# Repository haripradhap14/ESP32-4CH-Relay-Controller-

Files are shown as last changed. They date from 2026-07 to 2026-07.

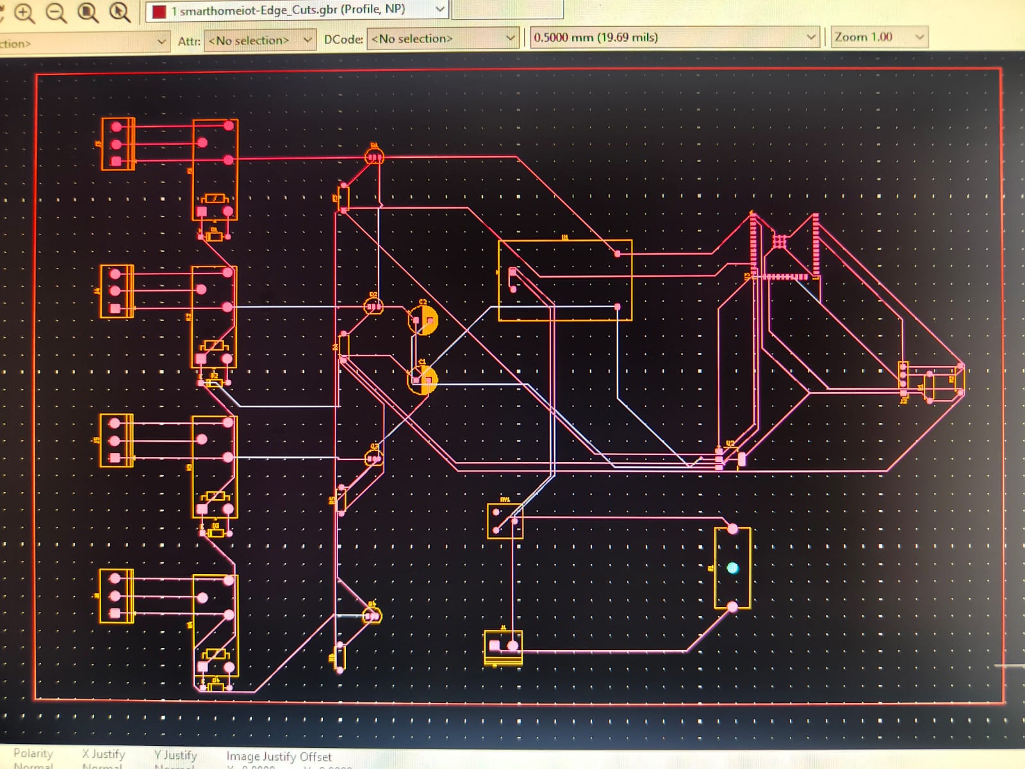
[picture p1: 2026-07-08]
Pcb_top_view.png.jpeg

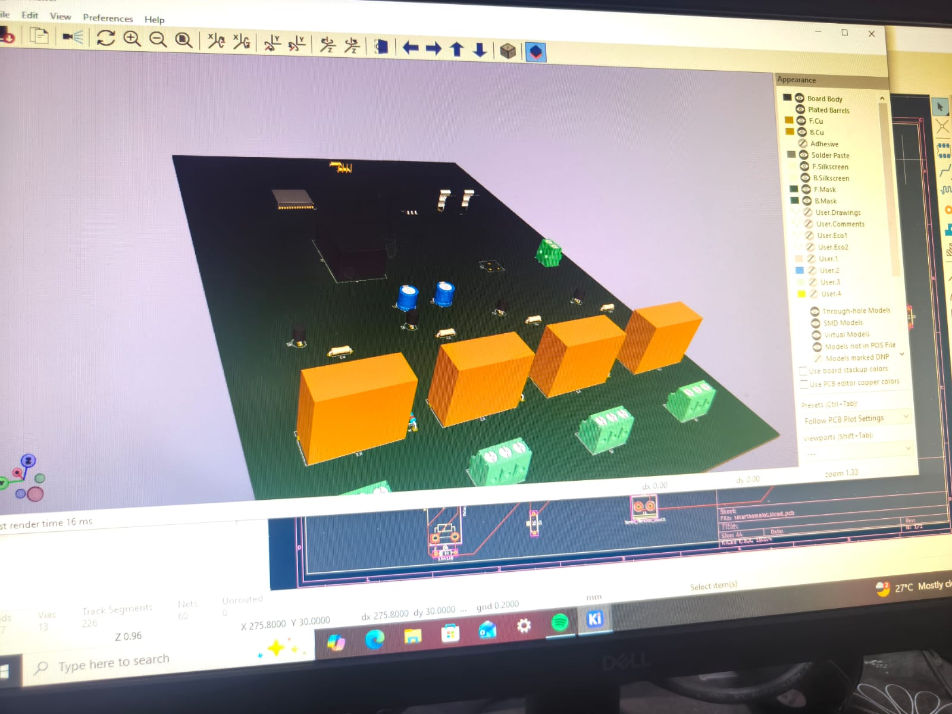
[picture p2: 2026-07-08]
Pcb_3d_render.png.jpeg

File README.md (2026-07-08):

# Smart Home Automation Controller (4-Channel Relay)

This project is a compact and integrated **Smart Home Automation Controller** designed using KiCad. It allows users to control household appliances remotely via Wi-Fi, leveraging the power of the ESP32-WROOM-32E module.

## 🚀 Key Features
* **Microcontroller:** ESP32-WROOM-32E (Integrated Wi-Fi & Bluetooth connectivity).
* **Power Management:**
    * Integrated AC-to-DC converter (230V AC to 5V DC).
    * High-efficiency 5V to 3.3V step-down regulator for stable power supply to the ESP32.
* **Control Unit:** 4-Channel Relay board to switch high-voltage home appliances (lights, fans, etc.).
* **Design:** Compact, single-board design suitable for wall-mount enclosures.
* **Flexibility:** The board is designed to be modular, allowing users to adapt inputs/switches based on specific smart home requirements.

## 🛠 Technical Specifications
* **Controller:** ESP32-WROOM-32E
* **Relay Channels:** 4 x High-quality relays with opto-isolation (for safety).
* **PCB Layers:** 2-Layer Board (FR4 material).
* **Design Software:** KiCad EDA.

## ⚠️ Safety Warning
This project involves dealing with **230V AC Mains voltage**. Please ensure all high-voltage connections are properly insulated and handled with extreme caution during testing and installation.

## 📂 Project Structure
* `/Schematic` - Contains the circuit design and architecture.
* `/PCB` - Contains the PCB layout (.kicad_pcb file).
* `/Gerbers` - Contains the manufacturing files (Gerber & Drill files) for PCB fabrication.

---
*Designed for home automation enthusiasts and IoT developers.*

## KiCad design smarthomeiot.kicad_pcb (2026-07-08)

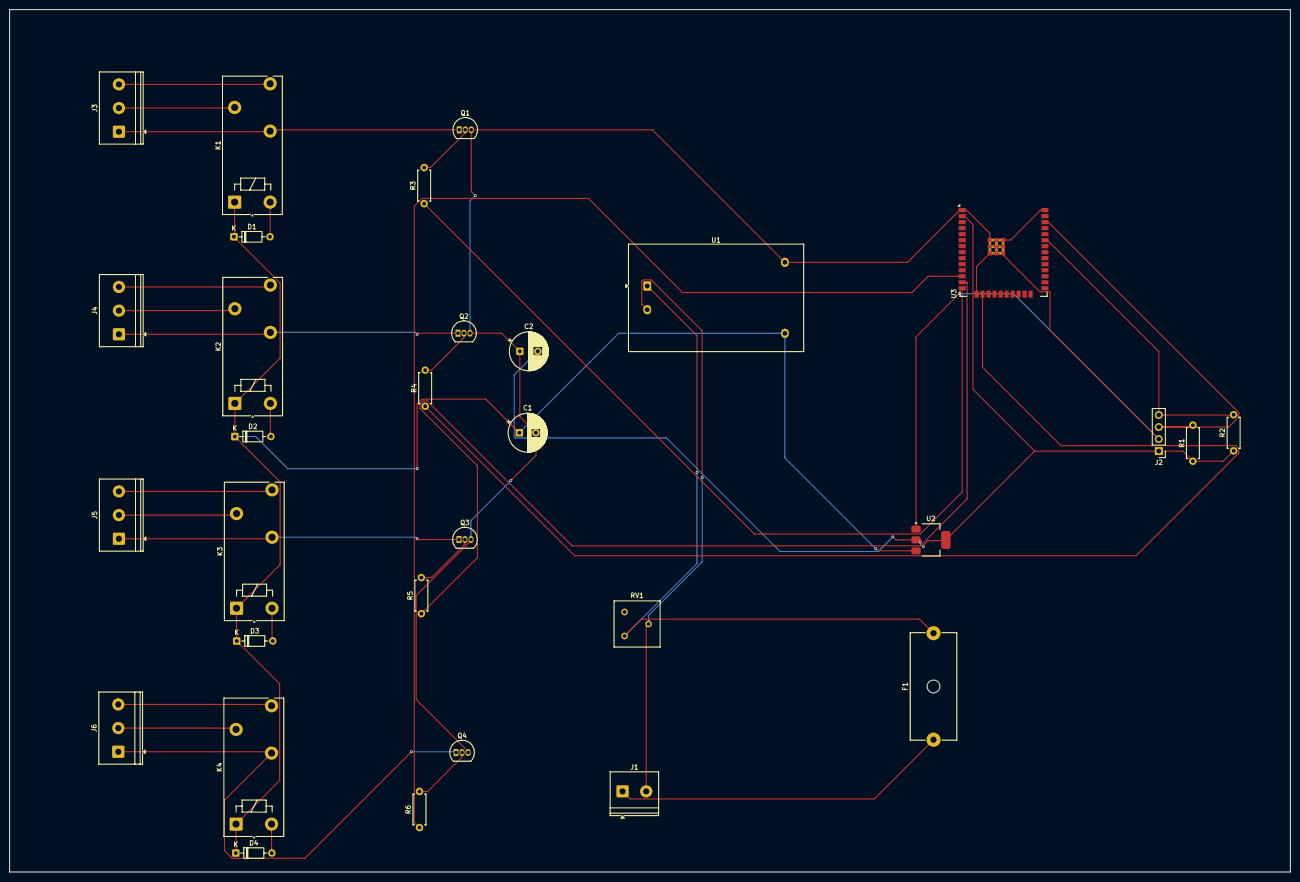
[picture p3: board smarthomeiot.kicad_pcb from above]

Board: 2 copper layers, 270.6 x 182.2 mm, 31 parts (0 on the bottom side), 32 nets.

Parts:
C1: 470uF/25V; CP_Radial_D8.0mm_P3.50mm
C2: 100uF/16V; CP_Radial_D8.0mm_P3.80mm
D1, D2, D3, D4: 1N4148; D_DO-35_SOD27_P7.62mm_Horizontal
F1: 500mA-1A; Fuseholder_Cylinder-5x20mm_Schurter_0031_8201_Horizontal_Op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
J1: Screw_Terminal_01x02; TerminalBlock_Phoenix_PT-1,5-2-5.0-H_1x02_P5.00mm_Horizontal
J2: Conn_01x04_Socket; PinHeader_1x04_P2.54mm_Vertical
J3, J4, J5, J6: Screw_Terminal_01x03; TerminalBlock_Phoenix_PT-1,5-3-5.0-H_1x03_P5.00mm_Horizontal
K1, K2, K3, K4: Relay_SPDT; Relay_SPDT_Finder_40.51
Q1, Q2, Q3, Q4: BC547; TO-92_Inline
R1, R2, R3, R4, R5, R6: 1k; R_Axial_DIN0207_L6.3mm_D2.5mm_P7.62mm_Horizontal
RV1: 275V Varistor; Potentiometer_Bourns_3386F_Vertical
U1: HLK-PM01; Converter_ACDC_Hi-Link_HLK-PMxx
U2: AMS1117-3.3; SOT-223-3_TabPin2
U3: ESP32-WROOM-32E

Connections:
+3V3: C2.2, J2.1, R1.1, R2.1, U2.2 (VO), U3.2 (VDD)
+5V: C1.1, D1.1 (K), D2.1 (K), D3.1 (K), D4.1 (K), K1.A1, K2.A1, K3.A1, K4.A1, U1.4 (+Vout), U2.3 (VI)
/ESP32_Controller/Relay_1: R3.1, U3.14 (IO12)
/ESP32_Controller/Relay_2: R4.1, U3.16 (IO13)
/ESP32_Controller/Relay_3: R5.1, U3.13 (IO14)
/ESP32_Controller/Relay_4: R6.1, U3.12 (IO27)
GND: C1.2, C2.1, J2.2, Q1.3 (E), Q2.3 (E), Q3.3 (E), Q4.3 (E), U1.3 (-Vout), U2.1 (GND), U3.1 (GND), U3.15 (GND), U3.38 (GND), U3.39 (GND)
unnamed: D1.2 (A), K1.A2
unnamed: D2.2 (A), K2.A2
unnamed: D3.2 (A), K3.A2
unnamed: D4.2 (A), K4.A2
unnamed: F1.1, J1.1
unnamed: J1.2, RV1.2, U1.2 (AC/N)
unnamed: J2.3, R1.2, U3.36 (IO22)
unnamed: J2.4, R2.2, U3.33 (IO21)
unnamed: J3.1, K1.12, Q1.1 (C)
unnamed: J3.2, K1.11
unnamed: J3.3, K1.14
unnamed: J4.1, K2.12, Q2.1 (C)
unnamed: J4.2, K2.11
unnamed: J4.3, K2.14
unnamed: J5.1, K3.12, Q3.1 (C)
unnamed: J5.2, K3.11
unnamed: J5.3, K3.14
unnamed: J6.1, K4.12, Q4.1 (C)
unnamed: J6.2, K4.11
unnamed: J6.3, K4.14
unnamed: Q1.2 (B), R3.2
unnamed: Q2.2 (B), R4.2
unnamed: Q3.2 (B), R5.2
unnamed: Q4.2 (B), R6.2
unnamed: F1.2, RV1.1, U1.1 (AC/L)
